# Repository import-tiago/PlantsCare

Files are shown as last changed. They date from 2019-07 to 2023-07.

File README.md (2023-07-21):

# PlantsCare
 

PlantsCare is an IoT device for ultra low power standalone capacitive soil moisture meter.

## Features
##### Controller Device / [16-bit, RISC, MSP430 FRAM-based Microcontroller](https://github.com/import-tiago/PlantsCare/blob/master/Hardware/3.%20Datasheets/MCU/MSP430%20-%20Datasheet.pdf)

##### Wireless Technology / [Bluetooth Low Energy - CSR1010](https://github.com/import-tiago/WorkshySwitch/blob/master/Hardware/3.%20Datasheets/BLE/CSR1010%20(BLE%20IC)%20-%20Datasheet.pdf)

##### Low Power Requirements / [CR2450 Battery Life > 2 years](https://github.com/import-tiago/PlantsCare/blob/master/Hardware/3.%20Datasheets/Battery/CR2450.pdf)

##### Hardware Project / [Autodesk EAGLE](https://www.autodesk.com/products/eagle/free-download)

##### Firmware Project / [Code Composer Studio (CCS)](http://www.ti.com/tool/CCSTUDIO)

## PCB Gerber Preview


## Schematic
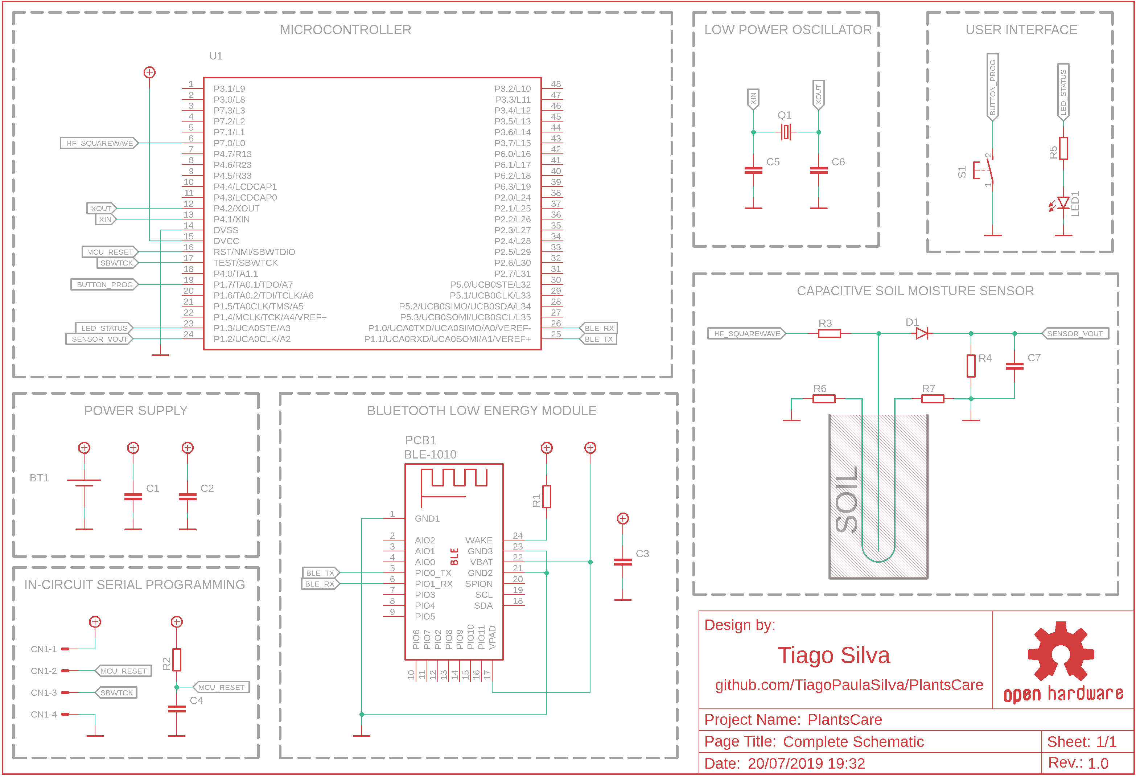
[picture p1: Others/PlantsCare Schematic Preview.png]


## Bill of Materials
| Qty | Parts | Description | Value | Package |
|--|--|--|--|--|
1|R2|SMD Resistor|47k ±5%|R0603
1|R4|SMD Resistor|1M ±5%|R0603
2|R6/R7|SMD Resistor|0R ±5%|R0603
3|R1/R3/R5|SMD Resistor|10k ±5%|R0603
1|C4|SMD Capacitor|1 nF / 50V|C0603
1|C7|SMD Capacitor|1 uF / 6.3V|C0603
1|C1|SMD Capacitor|10 uF / 50V|C0603
2|C2/C3|SMD Capacitor|100 nF / 50V|C0603
2|C5/C6|SMD Capacitor|22 pF / 50V|C0603
1|D1|Small Signal Fast Switching Diode|1N4148|SOD523
1|LED1|SMD LED|Blue|L0805
1|U1|Microcontroller|MSP430FR4133IG48R|TSSOP-48
1|Q1|SMD Crystal|32.768 kHz|3.2 x 1.5
1|PCB1|Qualcomm BLE CSRmesh Module|BLE-1010 MPCBA|-
1|BT1|Through Hole Coin Cell Battery Holder|CR2450|-
1|S1|SMD Switch/Momentary/Normally Open|SPST-NO|3 x 6 mm
1|CN1|Through Hole Connector/4 Pins/2 mm pitch|-|-

### Contributing
0. Give this project a :star:
1. Create an issue and describe your idea.
2. [Fork it](https://github.com/import-tiago/PlantsCare/fork).
3. Create your feature branch (`git checkout -b my-new-feature`).
4. Commit your changes (`git commit -a -m "Added feature title"`).
5. Publish the branch (`git push origin my-new-feature`).
6. Create a new pull request.
7. Done! :heavy_check_mark:

### License Information
<br /><span xmlns:dct="http://purl.org/dc/terms/" property="dct:title">PlantsCare</span> by <a xmlns:cc="http://creativecommons.org/ns#" href="https://github.com/import-tiago" property="cc:attributionName" rel="cc:attributionURL">Tiago Silva</a> is licensed under a <a rel="license" href="http://creativecommons.org/licenses/by-sa/4.0/">Creative Commons Attribution-ShareAlike 4.0 International License</a>.<br />Permissions beyond the scope of this license may be available at <a xmlns:cc="http://creativecommons.org/ns#" href="https://twitter.com/import_tiago" rel="cc:morePermissions">tiagodepaulasilva@gmail.com</a>.

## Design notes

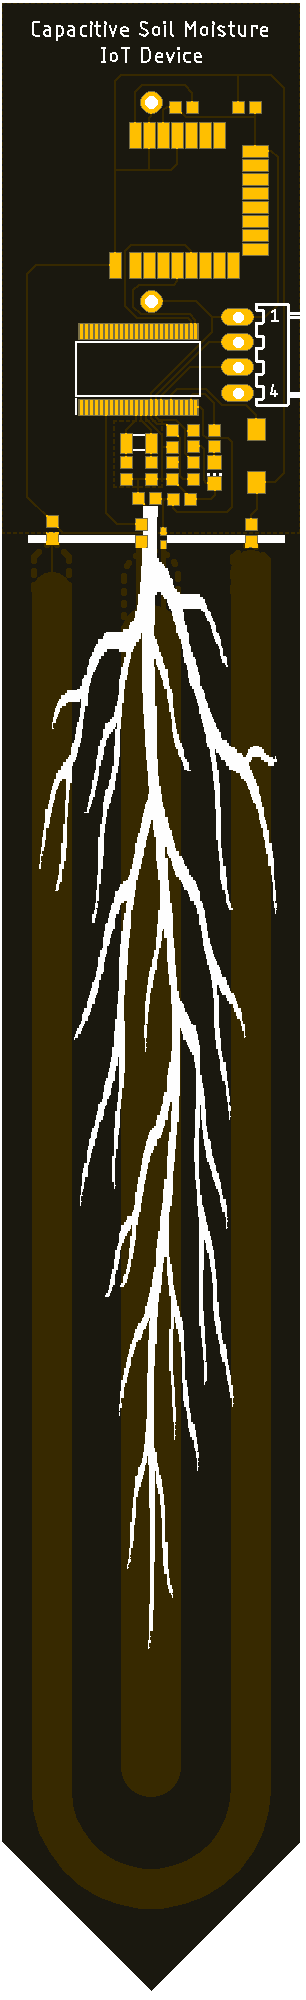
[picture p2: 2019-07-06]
Hardware/1. Mounting/PCB Preview.png

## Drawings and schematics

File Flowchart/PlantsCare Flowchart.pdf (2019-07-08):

# PlantsCare MCU Firmware main() Function Flowchart

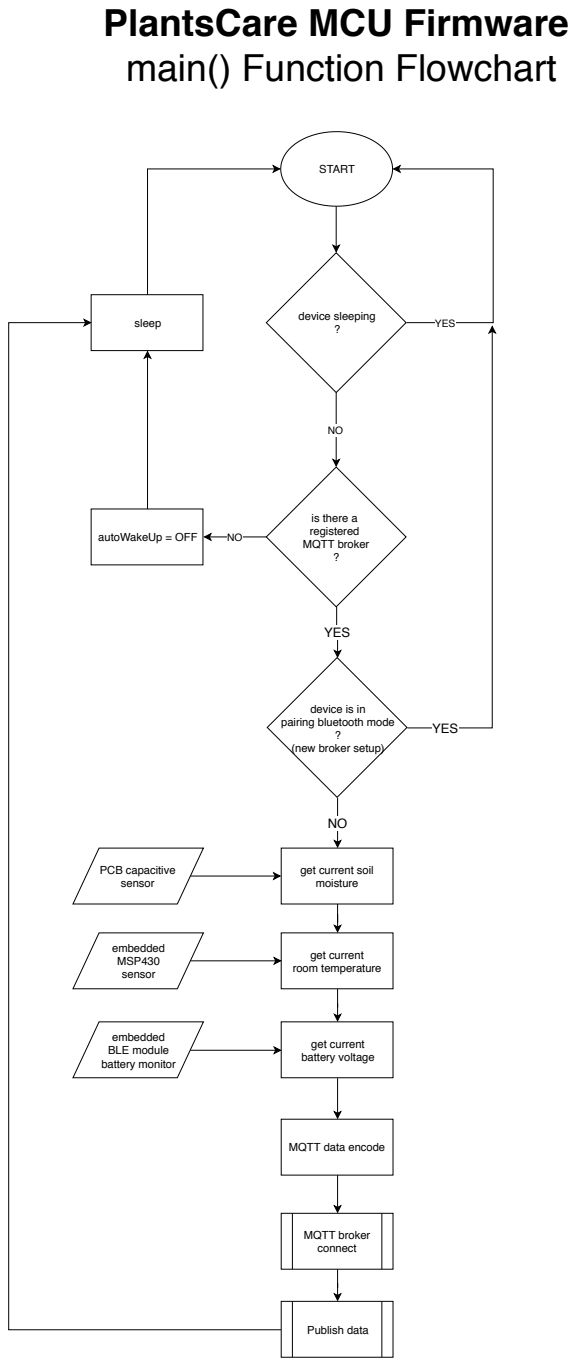
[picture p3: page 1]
START; YES; is there a registered MQTT broker ?; sleep; get current room temperature; get current battery voltage; MQTT broker connect; Publish data; autoWakeUp = OFF; PCB capacitive sensor; embedded MSP430 sensor; embedded BLE module battery monitor

YES device sleeping

device is in
pairing bluetooth mode

(new broker setup)

get current soil
moisture

MQTT data encode

# PlantsCare MCU Firmware Interrupt Services Routine Flowchart

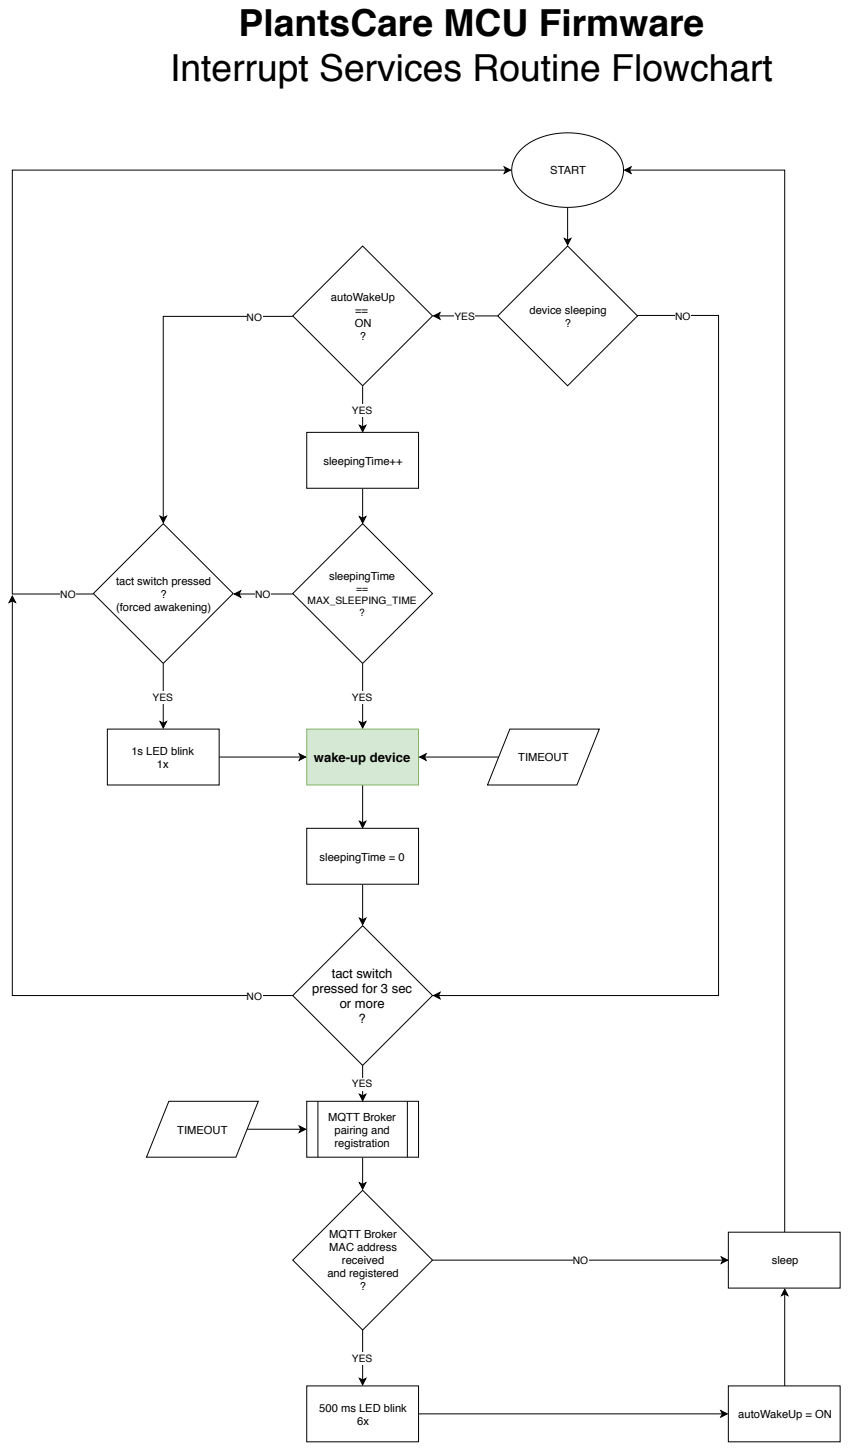
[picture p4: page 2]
START; YES; ? (forced awakening); 1s LED blink 1x; MQTT Broker pairing and registration; sleepingTime == MAX_SLEEPING_TIME ?; sleep; autoWakeUp = ON; sleepingTime++; sleepingTime = 0; MQTT Broker MAC address received and registered ?; TIMEOUT; NO device sleeping; autoWakeUp == ON ?

tact switch pressed

wake-up device

tact switch
pressed for 3 sec
or more

500 ms LED blink

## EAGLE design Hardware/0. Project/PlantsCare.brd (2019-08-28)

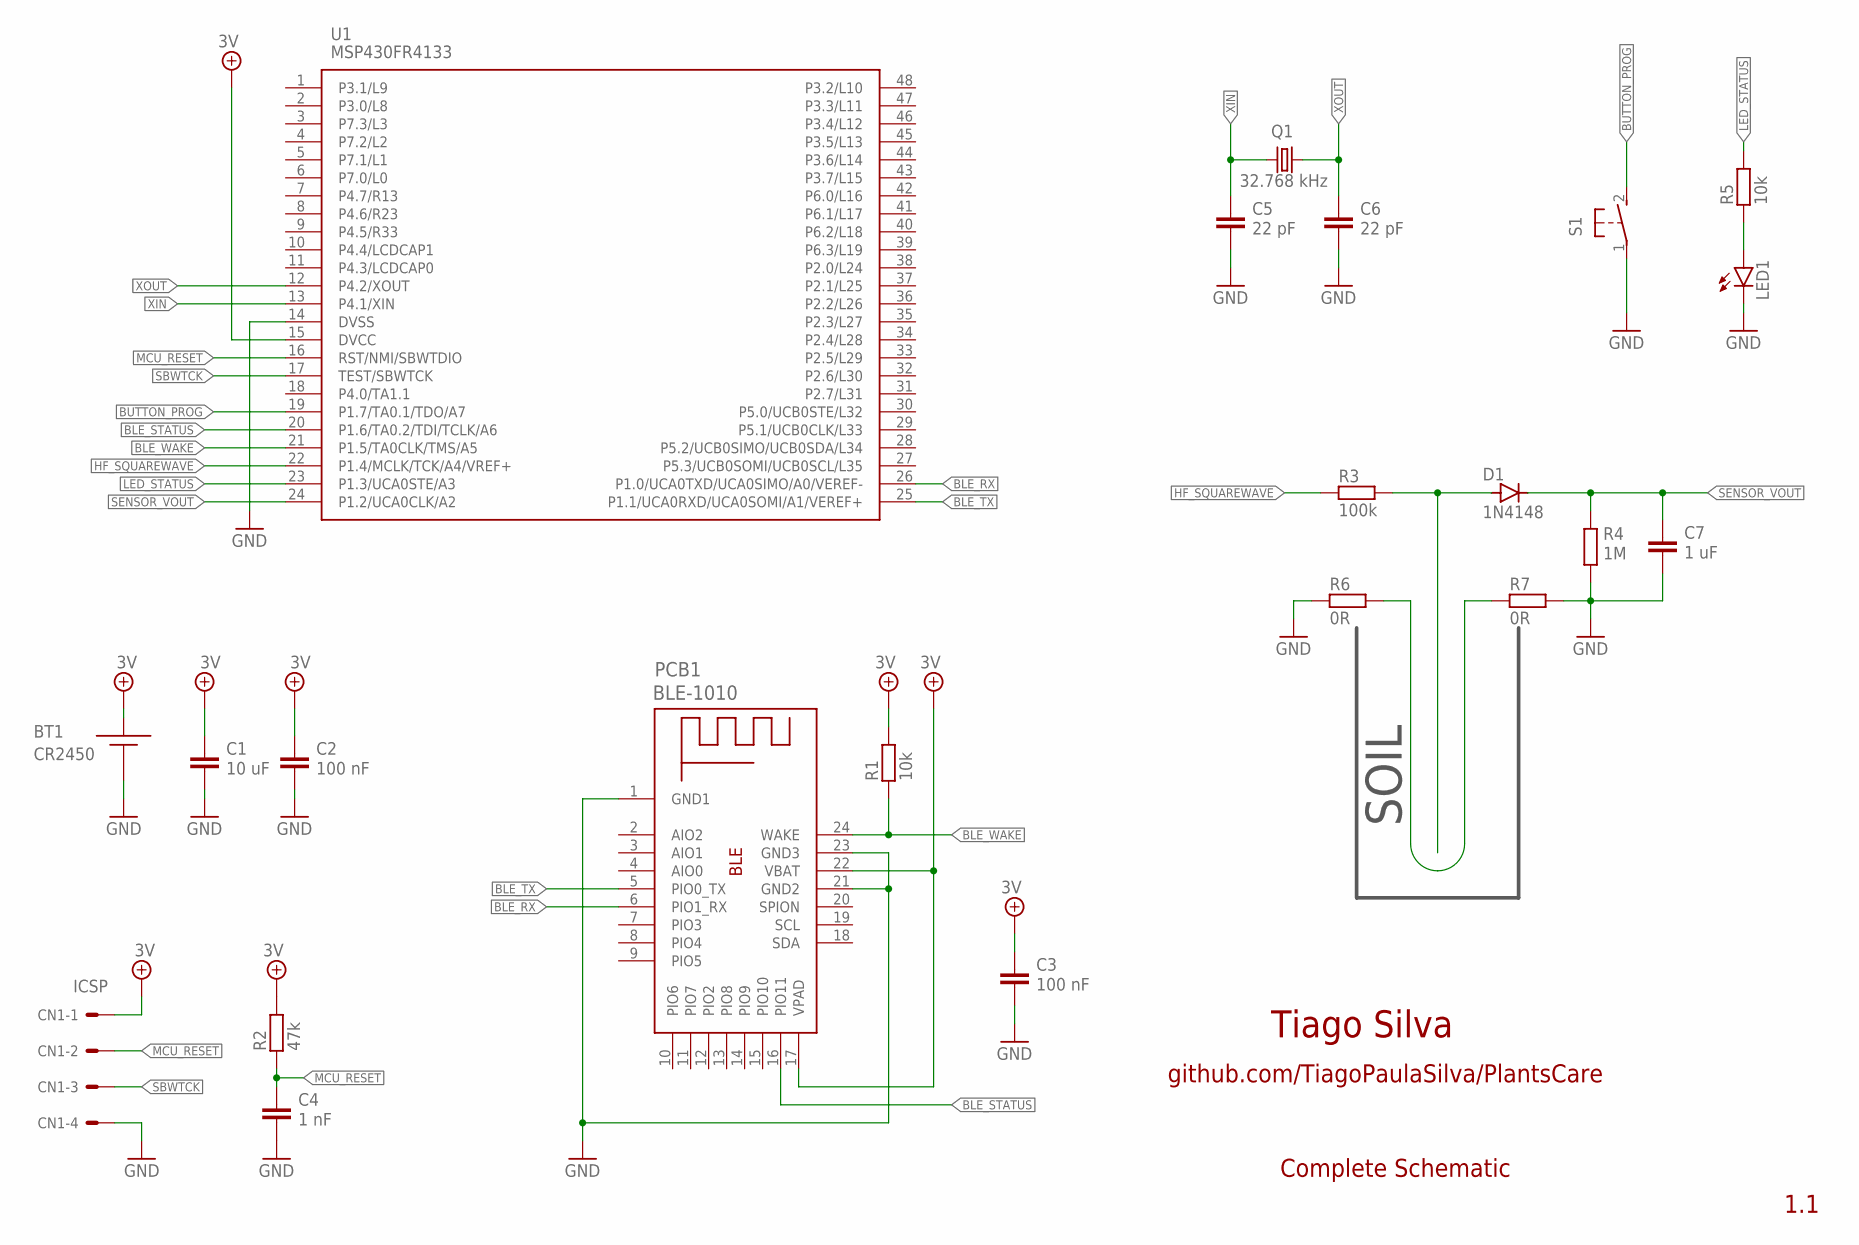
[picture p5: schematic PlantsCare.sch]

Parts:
BT1: CR2450; 1053
C1: 10 uF; C0603
C2, C3: 100 nF; C0603
C4: 1 nF; C0603
C5, C6: 22 pF; C0603
C7: 1 uF; C0603
CN1: ICSP; 7395-04
D1: 1N4148; SOD523
LED1: LEDCHIP-LED0805; CHIP-LED0805
PCB1: BLE-1010
Q1: 32.768 kHz; 3.2X1.5
R1, R5: 10k; R0603
R2: 47k; R0603
R3: 100k; R0603
R4: 1M; R0603
R6, R7: 0R; R0603
S1: DTSM-3
U1: MSP430FR4133; SOP50P810X120-48N

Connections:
3V: BT1.2 (3V), C1.1, C2.1, C3.1, CN1.1, PCB1.17 (VPAD), PCB1.22 (VBAT), R1.1, R2.1, U1.15 (DVCC)
BLE_RX: PCB1.6 (PIO1_RX), U1.26 (P1.0/UCA0TXD/UCA0SIMO/A0/VEREF-)
BLE_STATUS: PCB1.16 (PIO11), U1.20 (P1.6/TA0.2/TDI/TCLK/A6)
BLE_TX: PCB1.5 (PIO0_TX), U1.25 (P1.1/UCA0RXD/UCA0SOMI/A1/VEREF+)
BLE_WAKE: PCB1.24 (WAKE), R1.2, U1.21 (P1.5/TA0CLK/TMS/A5)
BUTTON_PROG: S1.2, U1.19 (P1.7/TA0.1/TDO/A7)
ELECTRODE_CAP1: R6.1, R7.2
ELECTRODE_CAP2: D1.A, R3.1
GND: BT1.1 (GND), C1.2, C2.2, C3.2, C4.2, C5.2, C6.2, C7.2, CN1.4, LED1.C, PCB1.1 (GND1), PCB1.21 (GND2), PCB1.23 (GND3), R4.2, R6.2, R7.1, S1.1, U1.14 (DVSS)
HF_SQUAREWAVE: R3.2, U1.22 (P1.4/MCLK/TCK/A4/VREF+)
LED_STATUS: R5.1, U1.23 (P1.3/UCA0STE/A3)
MCU_RESET: C4.1, CN1.2, R2.2, U1.16 (RST/NMI/SBWTDIO)
unnamed: LED1.A, R5.2
SBWTCK: CN1.3, U1.17 (TEST/SBWTCK)
SENSOR_VOUT: C7.1, D1.C, R4.1, U1.24 (P1.2/UCA0CLK/A2)
XIN: C5.1, Q1.1, U1.13 (P4.1/XIN)
XOUT: C6.1, Q1.2, U1.12 (P4.2/XOUT)

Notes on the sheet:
Tiago Silva
github.com/TiagoPaulaSilva/PlantsCare
SOIL
1.1
Complete Schematic

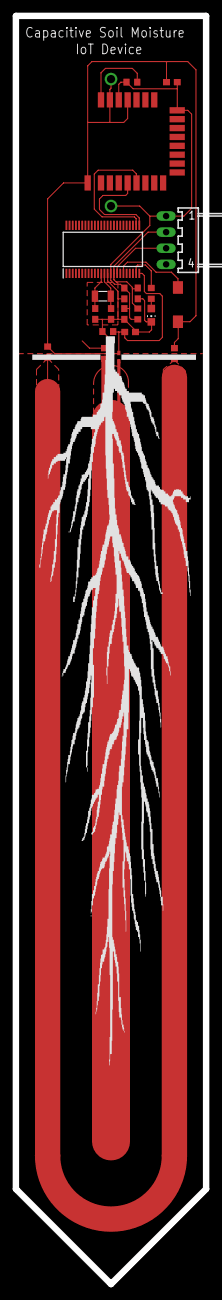
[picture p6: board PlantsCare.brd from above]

Board: 2 copper layers, 30.0 x 200.0 mm, 22 parts (0 on the bottom side), 17 nets.

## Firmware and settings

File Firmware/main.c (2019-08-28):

#include <msp430.h>
#include <string.h>
#include <stdio.h>
#include <stdlib.h>

#define HIGH                    1
#define LOW                     0
#define TRUE                    1
#define FALSE                   0

#define MASTER                  1
#define SLAVE                   0

#define ISR_TIMER0_A0_OFFSET    1045 // 1ms overflow
#define BUFFER_LENGTH           51

#define SHORT_DELAY             100    // 100ms
#define MEDIUM_DELAY            500    // 500ms
#define LONG_DELAY              1000   // 1s
#define NO_BLINKY               0      // Continuous mode

#define SHORT_TIMEOUT           1000   // 1s
#define MEDIUM_TIMEOUT          5000   // 5s
#define LONG_TIMEOUT            10000  // 10s

#define SHORT_BUTTON_PRESS      3000   // 3s
#define MEDIUM_BUTTON_PRESS     5000   // 5s
#define LONG_BUTTON_PRESS       10000  // 10s

//Capacitive Soil Moisture
#define N_SAMPLES               50
#define SENSOR_FULL_DRY         0
#define SENSOR_FULL_WET         1
#define SENSOR_CALIBRATION      2


//Button
#define DEBOUNCE_BUTTON_DELAY   5

//FRAM
#define FRAM_kL_CALIBRATION_ADDR   0x1800      // 7B -> 4b * 7 = 18b -> 0x181C
#define FRAM_kL_CALIBRATION_LEN    7

#define FRAM_kA_CALIBRATION_ADDR   0x1824      // 7B -> 4b * 7 = 18b -> 0x1838
#define FRAM_kA_CALIBRATION_LEN    7




#define FRAM_ERROR 0
#define FRAM_SUCCESS 1


//DEFINIO DOS ESTADOS DA MQUINA DE ESTADOS FINITA
typedef enum {
    STARTING = 0,
    GET_SOIL_MOISTURE,
    BROKER_CONNECT,
    CAPACITIVE_SENSOR_CALIBRATION,
} StatesFSM1;

StatesFSM1 stateFSM1;



/* GLOBAL VARIABLES */

// UART Peripheral
volatile unsigned char Buffer_UART[BUFFER_LENGTH];
unsigned int Index_UART;

// TIMER Peripheral
unsigned long timebase;

// ADC Peripheral
volatile unsigned char Buffer_ADC[BUFFER_LENGTH];
unsigned int Index_ADC;

//Soil Moisture
unsigned int Sensor_Value;
unsigned int Sensor_Dry_Value;
unsigned int Sensor_Wet_Value;
unsigned int Soil_Moisture;


//Capacitive Sensor
float kA_Calibration;
float kL_Calibration;
_Bool Calibration_Mode_Running;
_Bool Successful_LED_Notification;


// LED
unsigned int LED_Current_Period;
unsigned int LED_Setpoint_Period;

// Auxiliaries
volatile unsigned char array[BUFFER_LENGTH];

// Button
_Bool Current_Button_State;
_Bool Last_Button_State;
_Bool Reading_Button;
unsigned long lastTime;
unsigned short Button_Pressed_Time;
_Bool Short_Press_Detected;
_Bool Medium_Press_Detected;
_Bool Long_Press_Detected;



//DEFINIÇÃO DOS PINOS UTILIZADOS PELO uC
#define UART_TX_PIN                     BIT1 // P1.1
#define UART_RX_PIN                     BIT0 // P1.0

#define HIGH_FREQ_SQUAREWAVE_PIN        BIT4 // P1.4
#define SENSOR_CAPACITIVE_PIN              2 // P1.2

#define LED_STATUS_PIN                  BIT3 // P1.3
#define BUTTON_PIN                      BIT7 // P1.7


void init_TimerA0(void);
void Write_UART(unsigned char* sentence);
void init_UART(unsigned long _baudrate);
void init_GPIO(void);
void init_Oscillator(void);
void init_Watchdog(void);
void init_ADC(void);
void init_Global_Variables(void);
char* itoa(int value, char* result, int base);


unsigned char ADC_Read(void);
void ADC_Start(void);
void ADC_Stop(void);

void delay(unsigned int n);
void LED_Blink();
void LED_Blink_Successful(char _nBlink);
_Bool Write_Wait_Response(unsigned char* _command, char* _expected_answer, unsigned int _timeout);
void setup_BLE(_Bool HIERARCHY, char* newName);
unsigned int Get_Soil_Moisture();
unsigned int Get_Sensor_Value();
unsigned long millis();
void FRAM_Write(unsigned long *Write_Address, char* Write_Data, unsigned short Number_Bytes);
void FRAM_Read(unsigned long *Read_Address,  unsigned short Number_Bytes);
void ftoa(volatile float f, char * buf);
void Load_Calibration_Coefficients();
void Clear_Calibration_Coefficients();
void Save_Calibration_Coefficients(float kA, float kL);
void LED_State(char _state);
void Two_Points_Sensor_Calibration(volatile  int _Dry_Value, volatile  int _Wet_Value);
void Load_Default_Calibration_Coefficients();


int main(void){
    init_Watchdog();
    init_Oscillator();
    init_GPIO();
    init_ADC();
    init_TimerA0();
    init_UART(9600);
    init_Global_Variables();

    __bis_SR_register(GIE);


    Load_Default_Calibration_Coefficients();



    while(1)
    {
        runFSM();
    }
}

void Load_Default_Calibration_Coefficients(){
    Two_Points_Sensor_Calibration(182, 149);
    kA_Calibration = 0;
    kL_Calibration = 0;
}

void runFSM() {
    switch(stateFSM1) {
       case STARTING: {
           LED_Setpoint_Period = NO_BLINKY;
           Load_Calibration_Coefficients();
           stateFSM1 = GET_SOIL_MOISTURE;
           break;
       }

       case GET_SOIL_MOISTURE: {

           Soil_Moisture = Get_Soil_Moisture();

           sprintf((char*)array, "%d%s", Sensor_Value, "\r\n");
           Write_UART(array);


           sprintf((char*)array, "%d%s", Soil_Moisture, "\r\n");
           Write_UART(array);

           Write_UART("\r\r\n");

           delay(500);

           break;
       }

       case BROKER_CONNECT: {
           sprintf((char*)array, "%d%s", Soil_Moisture, "\n");
           Write_UART(array);
           delay(500);
           break;
       }

       case CAPACITIVE_SENSOR_CALIBRATION: {
           char _step = 0;
           do
           {
               switch(_step)
               {
                   case SENSOR_FULL_DRY:
                   {
                       do
                       {
                           Sensor_Dry_Value = Get_Sensor_Value();
                       }while((P1IN & BUTTON_PIN));

                       LED_Blink_Successful(10);
                       _step++;

                       break;
                   }

                   case SENSOR_FULL_WET:
                   {
                       do
                       {
                           Sensor_Wet_Value = Get_Sensor_Value();
                       }while((P1IN & BUTTON_PIN));

                       LED_Blink_Successful(10);
                       _step++;

                       break;
                   }
                   case SENSOR_CALIBRATION:
                   {
                       kA_Calibration = (100.0 / (Sensor_Wet_Value - Sensor_Dry_Value));
                       kL_Calibration = (kA_Calibration * Sensor_Dry_Value);

                       Save_Calibration_Coefficients(kA_Calibration, kL_Calibration);
                       LED_Blink_Successful(10);
                       LED_State(LOW);
                       Calibration_Mode_Running = FALSE;
                       break;
                   }
               }
           }while(Calibration_Mode_Running);

           stateFSM1 = STARTING;
           break;
       }

    }
}

void Two_Points_Sensor_Calibration(volatile  int _Dry_Value, volatile  int _Wet_Value) {

    Clear_Calibration_Coefficients();

    kA_Calibration = (100.0 / (float)(_Wet_Value - _Dry_Value));
    kL_Calibration = (kA_Calibration * _Dry_Value);

    Save_Calibration_Coefficients(kA_Calibration, kL_Calibration);
}

void Load_Calibration_Coefficients() {

    FRAM_Read(FRAM_kA_CALIBRATION_ADDR, FRAM_kA_CALIBRATION_LEN);
    kA_Calibration = atof(array);

    FRAM_Read(FRAM_kL_CALIBRATION_ADDR, FRAM_kL_CALIBRATION_LEN);
    kL_Calibration = atof(array);

    __no_operation();
}

void Clear_Calibration_Coefficients(){

    memset(array, '\0', sizeof(array));
    ftoa(0.00000, array);
    FRAM_Write(FRAM_kA_CALIBRATION_ADDR, array, FRAM_kA_CALIBRATION_LEN);

    memset(array, '\0', sizeof(array));
    ftoa(0.00000, array);
    FRAM_Write(FRAM_kL_CALIBRATION_ADDR, array, FRAM_kL_CALIBRATION_LEN);

    __no_operation();
}

void Save_Calibration_Coefficients(float kA, float kL){
    memset(array, '\0', sizeof(array));
    ftoa(kA, array);
    FRAM_Write(FRAM_kA_CALIBRATION_ADDR, array, FRAM_kA_CALIBRATION_LEN);
    __no_operation();

    memset(array, '\0', sizeof(array));
    ftoa(kL, array);
    FRAM_Write(FRAM_kL_CALIBRATION_ADDR, array, FRAM_kL_CALIBRATION_LEN);
    __no_operation();
}

void ftoa(volatile float f, char * buf) {

    volatile int intPart = 0;
    volatile int decPart = 0;

    intPart = f;
    f -= intPart;
    f *= 10000;
    decPart = f;

    if(decPart < 0)
        decPart  *= -1;

    if(decPart == 0)
        sprintf(buf, "%d.0000", intPart);
    else
        sprintf(buf, "%d.%d", intPart, decPart);

    __no_operation();
}

void FRAM_Read(unsigned long *Read_Address,  unsigned short Number_Bytes) {

    unsigned short i;
    memset(array, '\0', sizeof(array));

    for(i = 0; i < Number_Bytes; i++)
    {
      array[i] = *Read_Address++;
    }
}

void FRAM_Write(unsigned long *Write_Address, char* Write_Data, unsigned short Number_Bytes) {

    unsigned short i;


    __no_operation();

    SYSCFG0 &= ~DFWP; // Write Protection Disable

    for(i = 0; i < Number_Bytes; i++)
    {
      *Write_Address++ = Write_Data[i];
    }

    SYSCFG0 |= DFWP; // Write Protection Enable
}

unsigned int Get_Soil_Moisture(){
    char i;
    int _soil_moisture;

    for(i = 0; i < N_SAMPLES; i++)
        Sensor_Value += ADC_Read();


    Sensor_Value /= N_SAMPLES;

    _soil_moisture = (Sensor_Value * kA_Calibration) - kL_Calibration;
    __no_operation();

    if(_soil_moisture < 0)
        _soil_moisture = 0;
    if(_soil_moisture > 100)
        _soil_moisture = 100;

    return _soil_moisture;
}

unsigned int Get_Sensor_Value(){
    char i;

    Sensor_Value = 0;

    for(i = 0; i < N_SAMPLES; i++)
        Sensor_Value += ADC_Read();

    return Sensor_Value /= N_SAMPLES;
}

void init_Global_Variables(void){
    Buffer_UART[BUFFER_LENGTH-1] = '\0';
    Buffer_ADC[BUFFER_LENGTH-1] = '\0';

    Last_Button_State = 1;

    LED_Setpoint_Period = NO_BLINKY;

    Short_Press_Detected = FALSE;
    Medium_Press_Detected = FALSE;
    Long_Press_Detected = FALSE;

    Calibration_Mode_Running = FALSE;
    Successful_LED_Notification = FALSE;

    stateFSM1 = STARTING;
}

void init_Oscillator(void){
    P4SEL0 |= BIT1 | BIT2;                  // set XT1 pin as second function

    do
    {
        CSCTL7 &= ~(XT1OFFG | DCOFFG);           // Clear XT1 and DCO fault flag
        SFRIFG1 &= ~OFIFG;
    }while (SFRIFG1 & OFIFG);                    // Test oscillator fault flag

    __bis_SR_register(SCG0);                     // disable FLL

    CSCTL3 |= SELREF__XT1CLK;                    // Set XT1CLK as FLL reference source
    CSCTL0 = 0;                                  // clear DCO and MOD registers

    __bic_SR_register(SCG0);                     // enable FLL

    while(CSCTL7 & (FLLUNLOCK0 | FLLUNLOCK1));   // Poll until FLL is locked

    CSCTL7 &= ~DCOFFG;                           // Clear DCO fault flag
    CSCTL4 = SELMS__DCOCLKDIV | SELA__XT1CLK;  // set ACLK = XT1CLK = 32768Hz
                                               // DCOCLK = MCLK and SMCLK source
}

void init_Watchdog(void){
    WDTCTL = WDTPW | WDTHOLD;   // Stop watchdog timer
}

void init_GPIO(void) {

    /*  FIRST STEP: All pins as GPIO, OUTPUT at LOW level (LPM Optimization)       */
    P1DIR  = 0xFF;  //All pins as OUTPUT
    P1SEL0 = 0x00;  //All pins as GPIO
    P1OUT  = 0x00;  //All pins as LOW

    P2DIR  = 0xFF;  //All pins as OUTPUT
    P2SEL0 = 0x00;  //All pins as GPIO
    P2OUT  = 0x00;  //All pins as LOW

    P3DIR  = 0xFF;  //All pins as OUTPUT
    P3SEL0 = 0x00;  //All pins as GPIO
    P3OUT  = 0x00;  //All pins as LOW

    P4DIR  = 0xFF;  //All pins as OUTPUT
    P4SEL0 = 0x00;  //All pins as GPIO
    P4OUT  = 0x00;  //All pins as LOW

    P5DIR  = 0xFF;  //All pins as OUTPUT
    P5SEL0 = 0x00;  //All pins as GPIO
    P5OUT  = 0x00;  //All pins as LOW

    P6DIR  = 0xFF;  //All pins as OUTPUT
    P6SEL0 = 0x00;  //All pins as GPIO
    P6OUT  = 0x00;  //All pins as LOW

    P7DIR  = 0xFF;  //All pins as OUTPUT
    P7SEL0 = 0x00;  //All pins as GPIO
    P7OUT  = 0x00;  //All pins as LOW

    P8DIR  = 0xFF;  //All pins as OUTPUT
    P8SEL0 = 0x00;  //All pins as GPIO
    P8OUT  = 0x00;  //All pins as LOW


    /*  SECOND STEP: INPUT PINS         */
    P1DIR &= ~UART_RX_PIN;
    P1DIR &= ~SENSOR_CAPACITIVE_PIN;
    P1DIR &= ~BUTTON_PIN;

    /*  PULL-UP OR PULL-DOWN  */
    P1REN |= BUTTON_PIN; // Pull-up enable to push-button
    P1OUT |= BUTTON_PIN; // Pull-up enable to push-button

    /*  THIRD STEP: SECUNDARY FUNCTIONS  */
    P1SEL0 |= UART_TX_PIN | UART_RX_PIN;    // UART pins
    P1SEL0 |= SENSOR_CAPACITIVE_PIN;        // ADC pin
    P1SEL0 |= HIGH_FREQ_SQUAREWAVE_PIN;     // MCLK as OUTPUT
    P4SEL0 |= BIT1 | BIT2;                  // Crystal pins

    PM5CTL0 &= ~LOCKLPM5; // GPIO High-Impedance OFF
}

void init_TimerA0(void) {
    TA0CCR0   = (int)ISR_TIMER0_A0_OFFSET;                         // Add Offset to TACCR0
    TA0CTL   |= TASSEL__SMCLK | MC__CONTINOUS;    // SMCLK, continuous mode
    TA0CCTL0 |= CCIE;                             // TACCR0 interrupt enabled
}

void delay(unsigned int n) {
  for (; n > 0; n--){
    __delay_cycles(625);
  }
}

void Write_UART(unsigned char* sentence) {
    unsigned int size = strlen((char*) sentence);
    unsigned int i = 0;

    while(size > 0) {
        while(!(UCA0IFG & UCTXIFG));
        UCA0TXBUF = sentence[i++];
        size--;
    }
}

void init_UART(unsigned long _baudrate) {
    UCA0CTLW0 |= UCSWRST;
    UCA0CTLW0 |= UCSSEL__SMCLK;

    switch(_baudrate)
    {
        case 9600:
            UCA0BR0 = 6;
            UCA0BR1 = 0;
            UCA0MCTLW |= 0x20 + UCOS16 + UCBRF_8;
            break;

        case 115200:
            UCA0BR0 = 0x45;
            UCA0BR1 = 0x00;
            UCA0MCTLW = 0x4A;
            break;
    }

    UCA0CTLW0 &= ~UCSWRST;
    UCA0IE |= UCRXIE;
}

void ADC_Stop(void){
    ADCCTL0  &= ~ADCON;
    ADCIE    &= ~ADCIE0;
}

void ADC_Start(void){

    ADCCTL0 |= ADCENC;          // Sampling and conversion start
    ADCCTL0 |= ADCSC;
    while(ADCCTL1 & ADCBUSY);
}

unsigned char ADC_Read(void){

    ADC_Start();
    if(Index_ADC > 0)
        return Buffer_ADC[Index_ADC-1];
    else
        return Buffer_ADC[BUFFER_LENGTH-1];
}

void init_ADC(void){
    ADCCTL0  &= ~ADCENC;            // Disable ADC conversion (needed for the next steps)
    ADCCTL0  |= ADCSHT_12 | ADCON;  // ADC sample-and-hold time = 1024 ADCCLK cycles | ADC on
    ADCCTL1  |= ADCSHP;            // ADC sample-and-hold pulse-mode select = SAMPCON signal is sourced from the sampling timer
    ADCCTL2  |= ADCRES_1;             // 10-bit conversion results
    ADCMCTL0 |= ADCINCH_2;          // A2 ADC input select; Vref=AVCC
    ADCIE    |= ADCIE0;             // Enable ADC conv complete interrupt
}

char* itoa(int value, char* result, int base) {
    // check that the base if valid
    if (base < 2 || base > 36)
    {
        *result = '\0';
        return result;
    }
    char* ptr = result, *ptr1 = result, tmp_char;
    int tmp_value;
    do
    {
        tmp_value = value;
        value /= base;
        *ptr++ = "zyxwvutsrqponmlkjihgfedcba9876543210123456789abcdefghijklmnopqrstuvwxyz" [35 + (tmp_value - value * base)];
    }while (value);

    // Apply negative sign
    if (tmp_value < 0)
        *ptr++ = '-';
    *ptr-- = '\0';
    while(ptr1 < ptr)
    {
        tmp_char = *ptr;
        *ptr--= *ptr1;
        *ptr1++ = tmp_char;
    }
    return result;
}

void setup_BLE(_Bool _HIERARCHY, char* _new_name) {

    __bis_SR_register(GIE);

    unsigned char _slave_name[20];
    char _step = 0;

    //TODO: in PCB version 1.2 or later, changes this lines for BLE_STATUS checking
    Write_UART("AT+DROP\r"); delay(100);
    Write_UART("AT+DROP\r"); delay(100);
    Write_UART("AT+DROP\r"); delay(100);
    Write_UART("AT+DROP\r"); delay(100);

    sprintf((char*)_slave_name, "%s%s\r", "AT+NAME", (char*)_new_name);
    if(_HIERARCHY == SLAVE){
        _step = 0;
        do{
            switch(_step){
                case 0:
                    if(Write_Wait_Response("AT+RENEW\r", "OK", SHORT_TIMEOUT)) //Test UART connection
                        _step++;
                    break;

                case 1:
                    if(Write_Wait_Response("AT+MODE0\r", "OK", SHORT_TIMEOUT)) //Operation mode set as TRANSMITION only
                        _step++;
                    break;

                case 2:
                    if(Write_Wait_Response("AT+ROLE0\r", "OK", SHORT_TIMEOUT)) //Hierarchical function set as SLAVE
                        _step++;
                    break;

                case 3:
                    if(Write_Wait_Response("AT+RESET\r", "\r", MEDIUM_TIMEOUT)) //Reset BLE module to save all new configurations
                        _step++;
                    break;

                case 4:
                    if(Write_Wait_Response("AT+ADDR?\r", "\r", SHORT_TIMEOUT)) //Request MAC Address
                        _step++;
                    break;

                case 5:
                    if(Write_Wait_Response(_slave_name, "\r", SHORT_TIMEOUT)) // Set a new module name
                        _step++;
                    break;

                case 6:
                    if(Write_Wait_Response("AT+NAME?\r", "\r", MEDIUM_TIMEOUT)) // Checks the new name
                        _step++;
                    break;
            }
        }while(_step <= 6);
    }
    else if(_HIERARCHY == MASTER){
        _step = 0;
        do{
            switch(_step){
                case 0:
                    if(Write_Wait_Response("AT+RENEW\r", "OK", SHORT_TIMEOUT)) //Test UART connection
                        _step++;
                    break;

                case 1:
                    if(Write_Wait_Response("AT+NOTI1\r", "OK", SHORT_TIMEOUT)) //Notify when a connections has beens established
                        _step++;
                    break;

                case 2:
                    if(Write_Wait_Response("AT+MODE0\r", "OK", SHORT_TIMEOUT)) //Operation mode set as TRANSMITION only
                        _step++;
                    break;

                case 3:
                    if(Write_Wait_Response("AT+IMME0\r", "OK", SHORT_TIMEOUT)) //Starts working immediately after power-up
                        _step++;
                    break;

                case 4:
                    if(Write_Wait_Response("AT+ROLE1\r", "OK", SHORT_TIMEOUT)) //Hierarchical function set as MASTER
                        _step++;
                    break;

                case 5:
                    if(Write_Wait_Response("AT+RESET\r", "\r", MEDIUM_TIMEOUT)) //Reset BLE module to save all new configurations
                        _step++;
                    break;

                case 6:
                    if(Write_Wait_Response("AT+ADDR?\r", "\r", SHORT_TIMEOUT)) //Request MAC Address
                        _step++;
                    break;
            }
        }while(_step <= 6);
    }
}

_Bool Write_Wait_Response(unsigned char* _command, char* _expected_answer, unsigned int _timeout) {

    _Bool _answer = FALSE;
    unsigned long _previous_time;

    memset((void*)Buffer_UART, '\0', sizeof(Buffer_UART));
    Index_UART = 0;

    _previous_time = millis();

    do
    {
        Write_UART(_command);
        delay(_timeout/4);
        if (strstr((const char*)Buffer_UART, (const char*)_expected_answer) != NULL)
            _answer = TRUE;

    } while((_answer == FALSE) && ((millis() - _previous_time) < _timeout));

    __no_operation();

    return _answer;
}

void LED_Blink(){
    if(!Successful_LED_Notification)
    {
        LED_Current_Period++;

        if(LED_Current_Period == LED_Setpoint_Period){
            P1OUT ^= LED_STATUS_PIN;
            LED_Current_Period = 0;
        }
    }
}

void LED_State(char _state){
    if(_state == LOW)
        P1OUT &= ~LED_STATUS_PIN;
    else if(_state == TRUE)
        P1OUT |= LED_STATUS_PIN;
}

void LED_Blink_Successful(char _nBlink) {
    Successful_LED_Notification = TRUE;

    char i;

    for(i = 0; i < _nBlink; i++)
    {
        P1OUT ^= LED_STATUS_PIN;
        delay(250);
    }

    Successful_LED_Notification = FALSE;

}

unsigned long millis() {
    return timebase;
}
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

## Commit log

2019-07-06 Schematic frame info updated
    [Soil Moisture Meter (IoT Device).sch]
2019-07-06 PCB layout developed
    [Soil Moisture Meter (IoT Device).brd, Soil Moisture Meter (IoT Device).sch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]
2019-07-06 Hardware folder created
    [Soil Moisture Meter (IoT Device).brd, Soil Moisture Meter (IoT Device).sch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]
2019-07-06 Battery Silk Screen Removed
    [Soil Moisture Meter (IoT Device).brd, Soil Moisture Meter (IoT Device).sch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]
2019-07-06 Added gerber PCB image preview
    [Soil Moisture Meter (IoT Device).brd]
2019-07-06 PCB image preview resized
2019-07-07 Changed folder structure
    [BOM.csv, Soil Moisture Meter (IoT Device).brd, Soil Moisture Meter (IoT Device).sch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]
2019-07-07 Project name changed to 'PlantsCare'
    [BOM.csv, Bill of Materials (BOM).csv, PlantsCare.brd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]
2019-07-07 BOM .csv file formatted as GitHub needed
    [Bill of Materials (BOM).csv, PlantsCare.brd, PlantsCare.sch]
2019-07-07 BOM .csv file updated
    [Bill of Materials (BOM).csv]
2019-07-07 PlantsCare flowchart added
2019-07-08 Flowchart updated
2019-07-10 CR2450 Battery added
2019-07-20 Schematic organization improved
    [PlantsCare.sch]
2019-07-20 Schematic image generated
2019-08-10 LED Blinky Working
2019-08-14 ADC reading high freq. waveform working
2019-08-14 Schematic updated to 1.2 revision
    --------------------------------------------------------------------
    * HF_SQUAREWAVE signal removed from P7.0 and connected to P1.4
    - P1.4 has a native function thats provides a MCLK clock as OUTPUT. This way, isn't necessery manually generates a high freq. signal with another pin.
    --------------------------------------------------------------------
    * BLE_WAKE signal added to P1.5
    - This will allows the MCU wake-up the BLE with a single low level pulse.
    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
    [PlantsCare.sch]
2019-08-14 PCB layout needs to be updated to 1.2
    [PlantsCare.brd]
2019-08-16 R3 value changed to fix SENSOR_VOUT waveform
    [PlantsCare.sch]
2019-08-16 Calibration process bugs fixed
    [main.c]
2019-08-28 Minor improvemets
    [PlantsCare.brd]
2019-11-16 Gerber image updated

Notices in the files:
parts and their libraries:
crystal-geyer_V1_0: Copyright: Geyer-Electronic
